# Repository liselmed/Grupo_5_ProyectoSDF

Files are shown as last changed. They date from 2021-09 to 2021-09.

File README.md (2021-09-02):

# Grupo#5 Proyecto: Smart Dairy Farming
*Sistema de monitoreo de temperatura y pH mediante una aplicación móvil para el control de la salud de la vaca.*

## Integrantes:
* Farinango Salazar Pedro
* Medina Chalén Lissette Elvira

## Descripción
Este repositorio tiene los archivos necesarios para la simulación de un sensor bolus que mide la temperatura y pH dentro del estómago de una vaca (rúmen), donde dichos datos serán enviados a través del protocolo de comunicación zigbee hacia una estación base que tendrá el objetivo de enviar credenciales y los valores de los sensores a una base de datos remota por medio de internet para que posteriormente se pueda monitorear en una aplicación móvil a través de gráficas de temperatura y pH en función del tiempo.

## Archivos Proteus
En la carpeta "Simulaciones" se tendrán dos archivos Proteus que van a representar el sensor bolus y la estación base, cabe recalcar que la versión del software es de 8.11 y para la comunicación de los módulos XBee (COMPIM) se utilizó el programa 'Virtual Serial Port', finalmente, se tiene un documento pdf que explica las simulaciones de todo el proyecto realizado.

## Archivos para la configuración de la base de datos
Para la base de datos remota se utilizó el servidor 000Webhost gratuito que posee la herramienta PhpMyAdmin, en la carpeta 'Configuraciones_Base de Datos' se tiene cada uno de los documentos .php que deben ir en File Manager de 000Webhost, los cuales permitirán hacer las peticiones post y get a la base de datos. A su vez, se tiene un archivo pdf que explica la creación de las tablas en las bases de datos con sus respectivos disparadores y relaciones entre cada una de ellas.

## Aplicación móvil
La aplicación movil se realizó en el software Android Studio y para acceder a ella se debe descargar todos los archivos de la carpeta 'Proyecto-SDF' los cuales permitirán el monitoreo de la salud de una vaca a través de gráficas de temperatura y pH en función del tiempo.

## Explicación del proyecto
Finalmente, se tiene un archivo Link_Exposicion.txt en el cual se adjunta el link de Youtube con la explicación del proyecto de forma breve y las respectivas simulaciones en tiempo real.

## Proyecto Smart Dairy Farming
-Archivo Proteus del sensor bolus

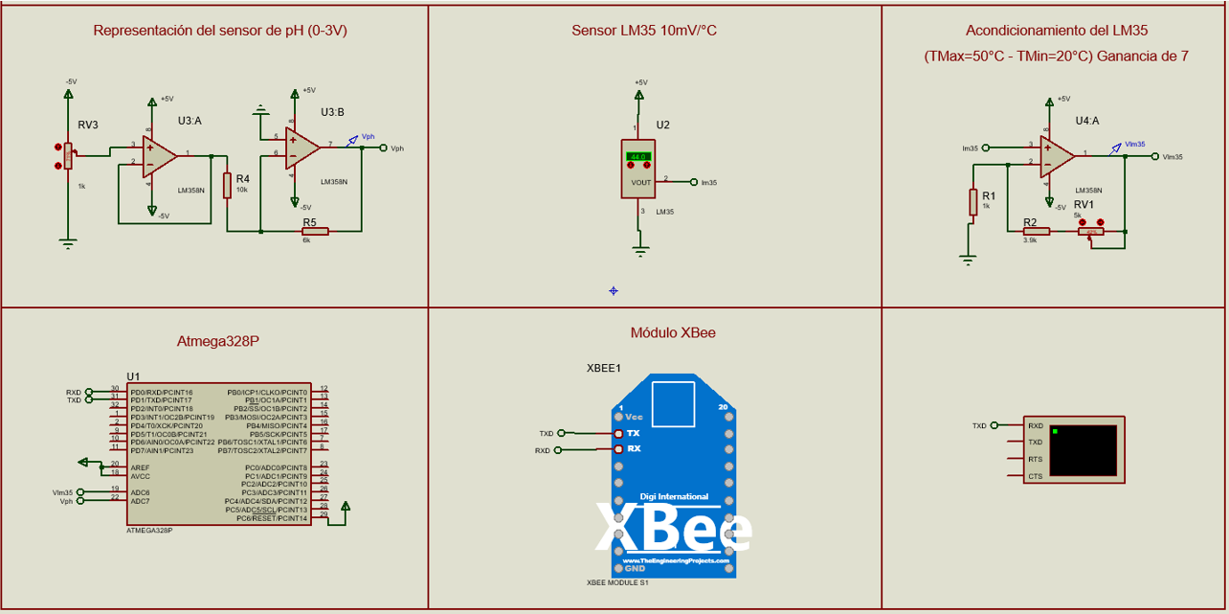
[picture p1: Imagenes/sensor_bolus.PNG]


-Archivo Proteus de la estación base

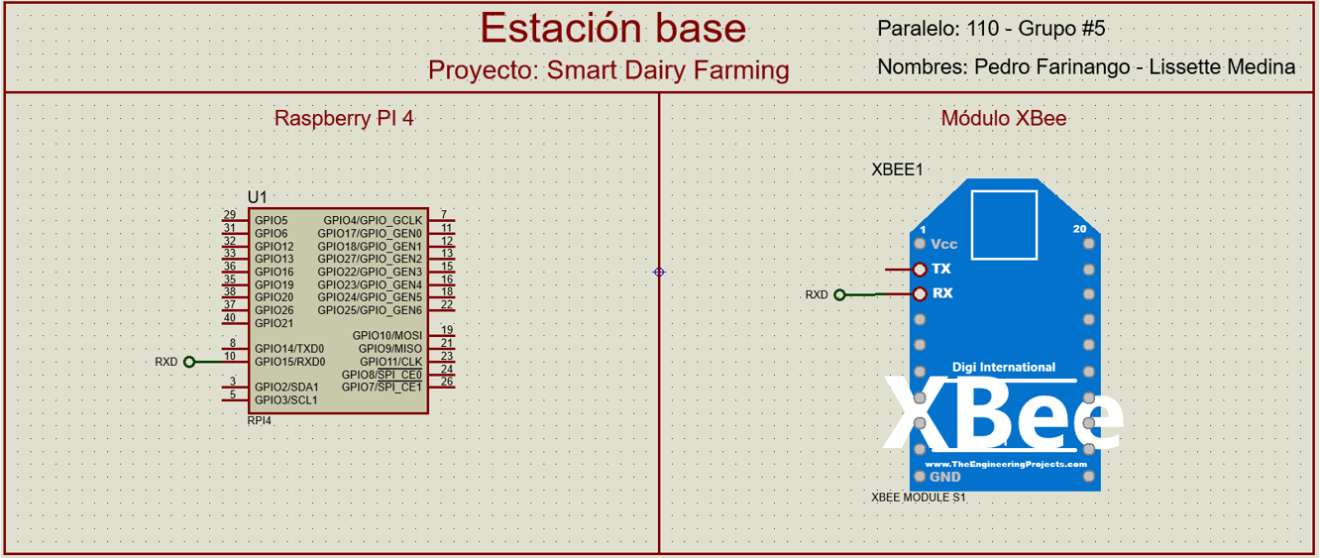
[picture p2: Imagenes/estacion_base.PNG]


-Aplición móvil en Android Studio

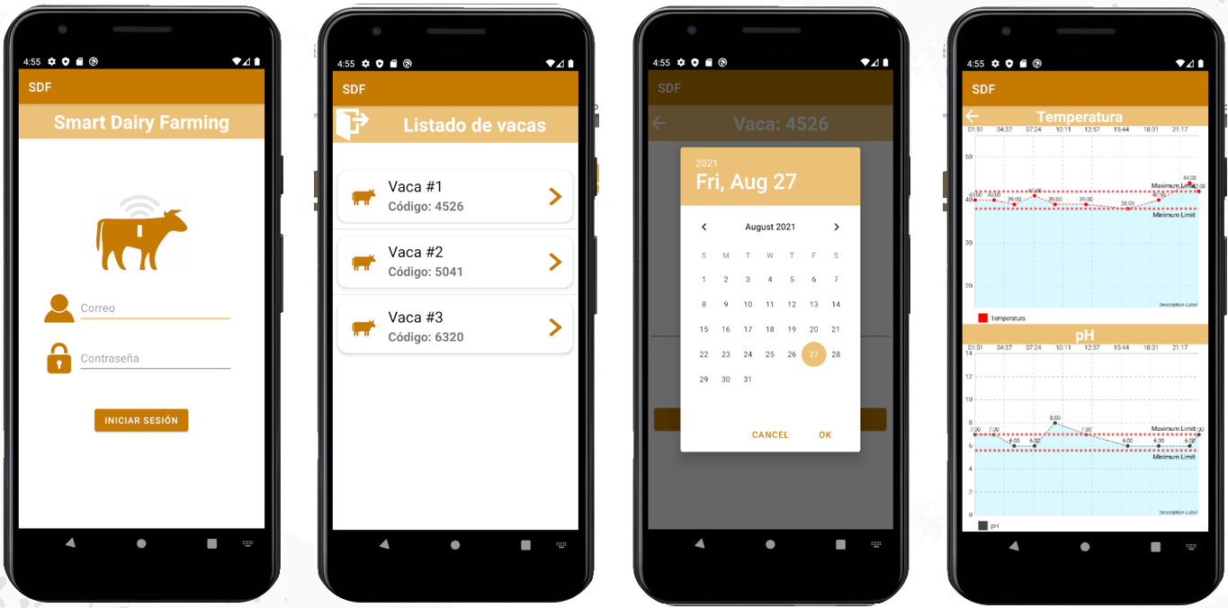
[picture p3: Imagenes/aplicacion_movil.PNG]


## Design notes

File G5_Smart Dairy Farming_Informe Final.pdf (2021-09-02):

SMART DAIRY FARMING | 1

Smart Dairy Farming: Health care

Farinango Salazar Pedro

Medina Chalen Lissette

Escuela Superior Politécnica del Litoral (ESPOL)

Facultad de Ingeniería en Mecánica y Ciencias de la Producción (FIMCP)

Notas del autor

Farinango Salazar Pedro, Estudiante de Ingeniería Mecatrónica, contacto: farinang@espol.edu.ec

Medina Chalen Lissette, Estudiante de Ingeniería Mecatrónica, contacto: liselmed@espol.edu.ec

Profesor Teórico: Allison Constantine

Profesor Práctico: Federico Domínguez

2021-1S

Introducción

Actualmente se buscan mejoras en los diferentes procesos industriales que realiza el ser

humano, una de ellas es la automatización, que surge debido a la gran demanda de los productos

que se consumen diariamente. En el caso de la industria lechera, gestionar una gran cantidad de

vacas supone algunos problemas para los encargados del ganado, debido a que se debe mantener

un control sobre el animal en diferentes aspectos, principalmente la salud. En este presente

proyecto se trata de detectar a través de parámetros como el pH y temperatura del rumen de la

vaca la enfermedad denominada Acidosis ruminal subclínica (SARA) que produce un

decaimiento en la digestibilidad de la fibra del rumen, y a su vez, tiene efectos negativos en el

rendimiento de la leche, como por ejemplo, la disminución de producción y su contenido de

grasa, de la misma manera se produce un costo elevado en la alimentación debido a la

deficiencia alimenticia producida por la SARA y, en el peor de los casos, la muerte del bovino.

La solución de este proyecto se basa en un sensor de pH y temperatura que estarán

envueltos en una resina a prueba de ácidos, la cual será insertada mediante una fístula ruminal

hasta llegar al rumen de la vaca, a través de eso se recopilan datos de los sensores

frecuentemente y son enviados mediante una conexión inalámbrica Zigbee hasta un Gateway,

que posteriormente traslada los valores a una nube y por medio de una aplicación móvil se

observan gráficas de temperatura y pH del rumen en función del tiempo, con la finalidad de

prevenir la SARA y así monitorear la salud de la vaca de forma precisa y eficiente.

Antecedentes

En la actualidad, la demanda de productos lácteos ha aumentado debido al crecimiento

poblacional. Según estudios anteriores, el consumo de productos lácteos está creciendo en países

subdesarrollados, donde el 80% de estos proviene de pequeños agricultores, los cuales no

cuentan con la tecnología necesaria para afrontar la mayor demanda del mundo.

Los productores de leche atraviesan limitaciones en cuanto a la gestión, capacidad de

producción y labores agrícolas correspondientes al ganado bovino, las cuales suponen un gran

costo. De acuerdo con estas limitaciones y desafíos, es necesario que el productor de leche

aumente su productividad y eficiencia abarcando recursos tecnológicos avanzados que le

permitan un monitoreo inteligente del manejo del ganado y así prevenir enfermedades, detectar

problemas de salud, entre otros.

Dentro de las investigaciones realizadas para el desarrollo de granjas lecheras inteligentes

se han considerado diferentes ontologías para permitir el análisis de datos y han implementado

proyectos que involucran sensores para monitorear diferentes actividades de las vacas, como es

el caso de SmartHerd, el cual analiza el comportamiento animal y control de la salud de la vaca,

los cuales constituyen el principal desafío para los productores de leche. Los autores describieron

diferentes áreas clave para el manejo de la fertilidad con ayuda de los sensores, ya que un buen

manejo de la fertilidad permitiría una mayor reproducción para de esa forma satisfacer la

creciente demanda del mercado.

Finalmente, las técnicas automatizadas en el ordeño, la alimentación y salud del bovino

son técnicas clave que pueden ser el futuro de una granja lechera inteligente y, a su vez, la razón

de una mayor producción de leche.

Objetivos

Objetivo General

Monitorear la salud y optimizar la alimentación de las vacas a través de la medición de

temperatura y pH dentro del rumen para la detección de SARA.

Objetivos Específicos

- Representar el funcionamiento de un sensor bolus mediante el uso de dos sensores de

temperatura y pH para la medición de los parámetros respectivos y el control de la salud de la

vaca.

- Registrar y transmitir los datos de temperatura y pH del rumen mediante el protocolo de

comunicación inalámbrica ZigBee para su visualización en una aplicación móvil.

- Determinar el efecto en la eficiencia alimenticia de tres vacas a través de la variación en el

aporte de nutrientes utilizando los datos obtenidos de un sensor de temperatura y de pH en una

aplicación móvil.

Smart Dairy Farming: Health care

Problemática

La ganadería lechera puede estar expuesta a enfermedades y por ende controlar cada

animal de forma continua es complicado, debido a que requiere mucho tiempo, y esto, es un

factor determinante en el cuidado de las vacas. Una de las enfermedades más comunes y que

repercute en la producción de la leche es la acidosis ruminal subclínica (SARA) (Osama, 2020),

la cual es un trastorno metabólico y nutricional difícil de diagnosticar que provoca la

disminución del pH del rumen con valores menores a 5.6 y un aumento en la temperatura mayor

a 42 °C (Omar Araujo, 2007). Dicha enfermedad afecta la eficiencia alimenticia y disminuye la

producción de leche y su contenido de grasa, por lo que los costos de alimentación incrementan

debido a que cada disminución de pH de 0.1 reduce la digestibilidad de la fibra en 3.6% (Cardo,

2020), cabe recalcar que episodios breves de 30 minutos de SARA no influyen directamente en

la reducción de la digestibilidad de la fibra sino en intervalos de 3 o 4 horas.

Descripción de por qué escogió la solución

En el Ecuador, la creciente demanda de productos lácteos ha generado complicaciones en

la gestión del ganado dentro del sector de ganadería lechera, donde los pequeños productores de

leche no cuentan con las herramientas necesarias para satisfacer dicha demanda, por lo que un

control inteligente de la vaca supone un gran aporte para estas personas, las cuales podrían

monitorear de forma continua la temperatura y pH de sus vacas para detectar tempranamente

enfermedades como el SARA, y de esa forma evitar gastos en los costos alimenticios y pérdidas

que afecten la producción lechera, ya que el SARA conlleva a otras enfermedades y también

pérdidas económicas en la industria lechera, con costos estimados en alrededor de USD 1.12 por

día y por vaca afectada (Nutrex, 2021).

De esta manera se podría ayudar a los productores a obtener un historial de la salud de

sus vacas y a tomar las medidas necesarias para evitar consecuencias graves, ya que actualmente

se aplican métodos tradicionales que implican mayores gastos y recursos, además de provocar

estrés e incomodidad en el bovino.

Finalmente, el proyecto como tal no se ha implementado en el país, por lo que sería una

propuesta innovadora.

Descripción de los elementos

Selección

De acuerdo con los elementos seleccionados, los cuales se encuentran detallados en la

Tabla 1 de la sección Tablas, se pretende diseñar dos tipos de carcasas que estarán ubicadas

dentro del rumen de la vaca y otra en la estación base (Gateway). La carcasa dentro de la vaca

consiste en un dispositivo cilíndrico (bolus) hecho de polioximetileno (POM) y recubierto con

una resina a prueba de ácidos (moonsyst International, 2021), esta carcasa tendría una protección

IP57, ya que los elementos estarán encapsulados, pero los sensores de temperatura y pH no

estarán completamente cubiertos.

Ilustración 1. Representación del dispositivo Bolus.

La carcasa ubicada en la estación base para la comunicación inalámbrica consiste en un

termoplástico de material ASA con una protección IP51, debido a que el dispositivo no estará

completamente cubierto porque tendría puertos abiertos para la alimentación de la Raspberry Pi

y la conexión ethernet.

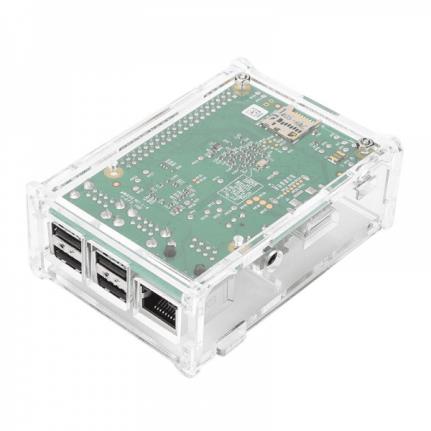
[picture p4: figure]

Ilustración 2. Carcasa para Raspberry Pi.

Componentes de hardware y software

Componentes de hardware:

El bolus, el cual será insertado en el rumen de la vaca, contiene los sensores de temperatura y de

pH, el atmega328P, el módulo XBee y la batería recargable de 5V de material Litio-polímero.

Los sensores se encargarán de medir la temperatura y el pH del rumen en intervalos de 15

minutos, tiempo determinado según un estudio previamente hecho sobre la relación entre pH y la

temperatura en el fluido ruminal para detectar cambios sobre una acidosis ruminal inducida

(Pedro García, 2015).

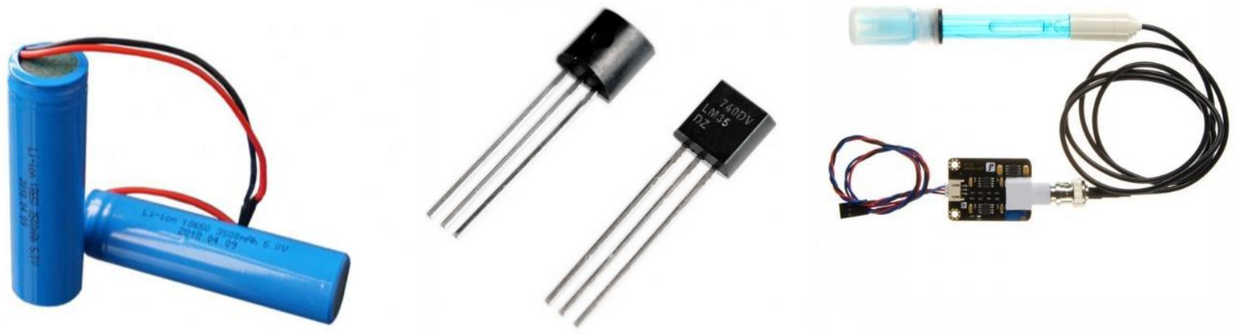
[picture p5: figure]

a) | b) | c)

Ilustración 3. a) Batería de 5V, b) Sensor LM35, c) Sensor pH SEN0161.

Los valores analógicos de los sensores serán procesados por el microcontrolador Atmega328P

para luego ser receptados por el módulo XBee End Device.

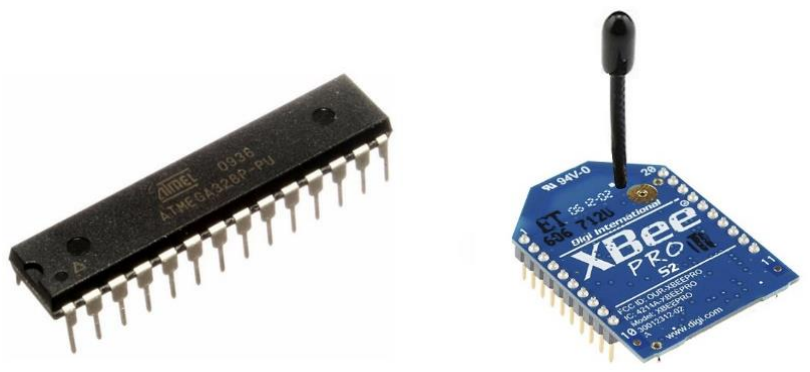
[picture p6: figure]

a) b)

Ilustración 4. Microcontrolador ATmega328P, b) Módulo Xbee End Device.

Posteriormente se da la comunicación Zigbee entre el dispositivo final y un módulo XBee

Coordinador que servirá para almacenar los datos enviados, este estará en la estación base

conectado a una Raspberry Pi para transmitir la información de los sensores a una base de datos.

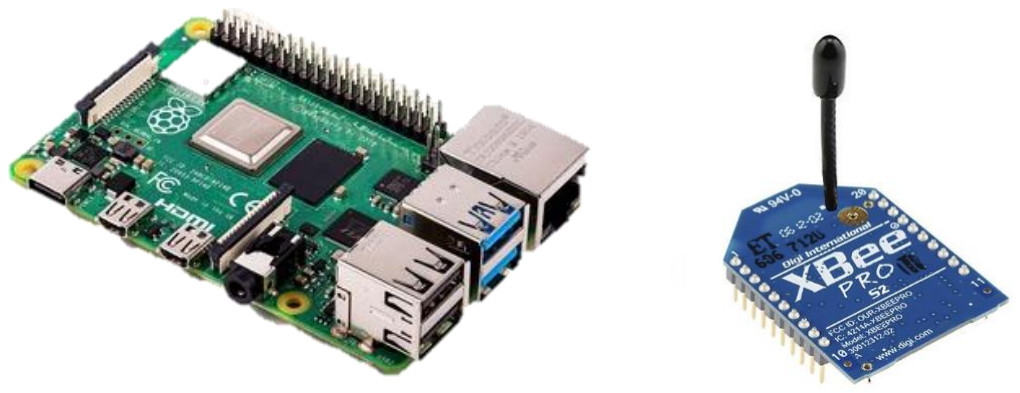
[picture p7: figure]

a) b)

Ilustración 5. a) Raspberry Pi 4, b) Módulo Xbee Coordinador.

Componentes de software:

Para la simulación del sistema de monitoreo y transmisión de datos se usará el software Proteus,

con el inconveniente de que se tendrá que utilizar un potenciómetro para representar el sensor de

pH con su respectivo acondicionamiento, debido a que en Proteus no se encuentra ningún sensor

de este tipo.

Para la gestión de base de datos se usará phpMyAdmin en la página 000WebHost.com,

posteriormente la información será enviada a una aplicación móvil creada en el software Android

Studio para el monitoreo de las condiciones del rumen de la vaca mediante la visualización de

los datos de temperatura y pH en tiempo real.

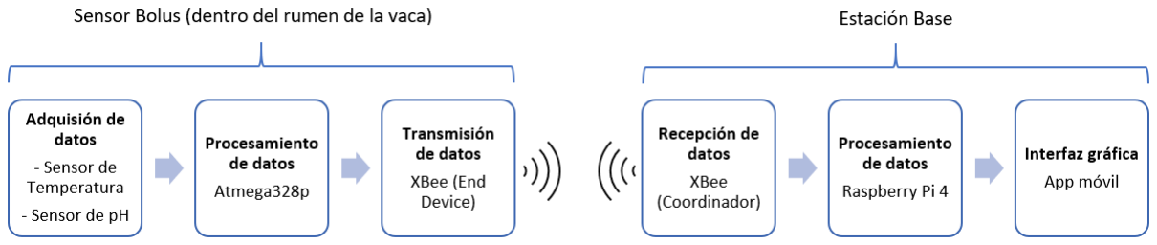
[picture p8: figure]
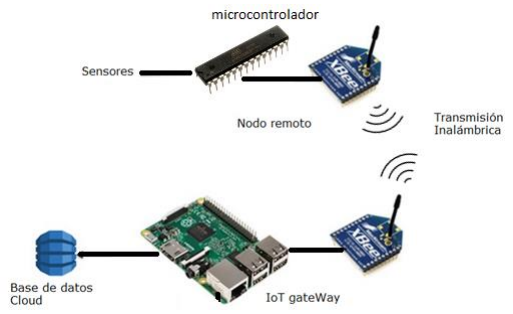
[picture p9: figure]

Ilustración 6. Diagrama de bloques del monitoreo y transmisión de datos.

Tabla de componentes y precios

La lista de los componentes con sus precios se encuentra en la Tabla 1 de la sección

Tablas.

Instalación y diseño

La fabricación de las carcasas para el sensor Bolus y la estación de base podrían hacerse

en https://www.plastinmega.com/.

Además, de acuerdo con el diseño de los PBCs realizados, la impresión de los mismos se

cotizó en la página JLCPCB (https://jlcpcb.com/) y su obtuvieron los siguientes precios:

PCB: Sensor bolus (Sensor de pH y temperatura, XBee End Device, ATmega328P,

batería)

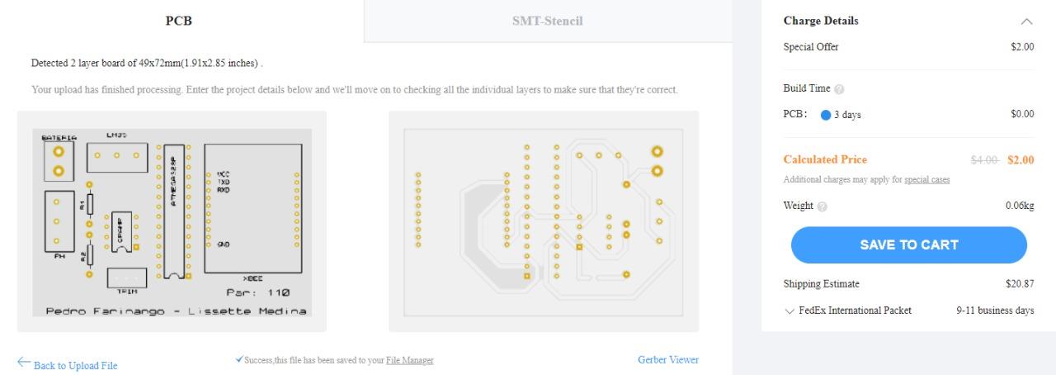
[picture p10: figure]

PCB: Estación base (Raspberry Pi 4, XBee coordinador)

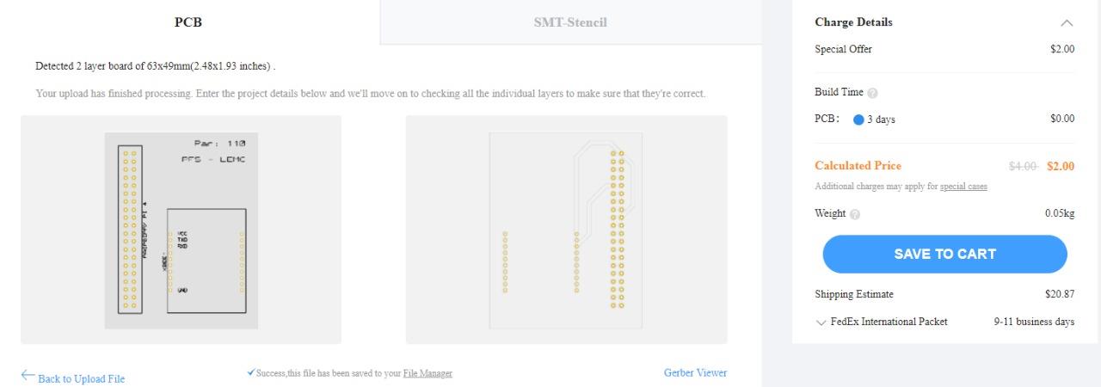
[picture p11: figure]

Aplicaciones a futuro

Se pretende realizar mejoras como:

- Ampliar la cobertura inalámbrica a través de repetidores de señal para el caso de

granjas con terrenos amplios.

- Suplir la batería recargable actual por una de mayor capacidad para una larga

duración dentro del rumen de la vaca.

- Compatibilidad con iOS e implementación en la web.

- Implementar una base de datos local en granjas lecheras que no tengan acceso a

internet.

Conclusiones

Se representó el funcionamiento de un sensor bolus mediante el uso de sensores de

temperatura y pH para la obtención de dichos parámetros y por ende controlar la salud de la

vaca, de manera que se midieron los valores analógicos de ambos sensores mediante el

microcontrolador ATmega328P para posteriormente realizar una comunicación serial con un

módulo XBee y enviar la información a una estación base.

Se realizó el acondicionamiento de las señales analógicas de los sensores de pH y

temperatura para la correcta lectura y conversión de dichos valores en el ATmega328P.

Se representó una estación base mediante la Raspberry PI 4 y un módulo XBee

coordinador para el registro y transmisión de los datos de temperatura y pH del rumen de la vaca

hacia una base de datos y visualizarlos en una aplicación móvil.

Se obtuvieron las gráficas de temperatura y pH del rumen de la vaca en función del

tiempo mediante una aplicación móvil que permitió el análisis del efecto en la eficiencia

alimenticia de tres vacas a través de una disminución del pH.

Recomendaciones

Es recomendable que, al realizar las mediciones de temperatura y pH mediante los

sensores, se analice correctamente los puertos analógicos a utilizar en el ATmega328P para de

esa forma habilitar los registros correspondientes que permitan la lectura y conversión analógica

de dichos valores.

Es importante entender que, en la vida real, el registro de lectura se cada 15 minutos y el

período de tiempo para determinar si existe o no la enfermedad de SARA requiere que las condiciones se presentan al menos durante 3 horas, por lo que es recomendable que en la

simulación se evidencie dicho tiempo para realizar el respectivo análisis.

Para el funcionamiento de la aplicación móvil, es importante que se realicen

correctamente las peticiones POST y GET en la Raspberry Pi y en la aplicación Android

respectivamente para obtener los datos de pH y temperatura y realizar las gráficas sin ningún

error.

Es recomendable establecer correctamente la ganancia necesaria en el acondicionamiento

de las señales analógicas para obtener una buena resolución en los valores medidos por el

ATmega328P.

References

Osama, M., Saad, M., Jamshaid, M., Qaiser, G. and Pasha, M., 2020. IoT for Development of

Smart Dairy Farming. [online] Pakistan: Maria Rosaria Corbo. Available at:

<https://doi.org/10.1155/2020/4242805> [Accessed 9 July 2021].

Araujo, O. and Vergara, J., 2021. Propiedades físicas y químicas del rumen. [online]

Bioline.org.br. Available at: <http://www.bioline.org.br/pdf?la07044> [Accessed 9 July

2021].

Pardo, L., 2020. Cómo abordar la acidosis y los peligros de la SARA. [online] biomin.net.

Available at: <https://bmeditores.mx/ganaderia/como-abordar-la-acidosis-y-los-peligros-

de-la-sara/> [Accessed 9 July 2021].

Real, L., 2019. Industria Láctea con mejores condiciones de producción. Gestión digital, [online]

(226), pp.36-39. Available at:

<https://revistagestion.ec/sites/default/files/import/legacy_pdfs/226_004.pdf> [Accessed

10 July 2021].

Nogami, H., Arai, S., Okada, H., Zhan, L. and Itoh, T., 2017. Minimized Bolus-Type Wireless

Sensor Node with a Built-In Three-Axis Acceleration Meter for Monitoring a Cow’s

Rumen Conditions. [online] MDPI. Available at: <https://doi.org/10.3390/s17040687>

[Accessed 11 July 2021].

Ibarra, N., 2015. Desarrollo de un sistema de monitoreo intra-rumial en tiempo real de variables

fisiológicas para ser empleado en estudios sobre adaptación bovina ante el cambio

climático en la ganadería tropical del sureste mexicano. [online]

Repositorioinstitucional.buap.mx. Available at:

<https://repositorioinstitucional.buap.mx/handle/20.500.12371/2283> [Accessed 11 July

2021].

International, M., 2021. Moonsyst - Smart Rumen Bolus. [online] Moonsyst. Available at:

<https://moonsyst.com/bolus> [Accessed 15 July 2021].

Wiki.dfrobot.com. 2021. Gravity__Analog_pH_Sensor_Meter_Kit_V2_SKU_SEN0161-V2-

DFRobot. [online] Available at:

<https://wiki.dfrobot.com/Gravity__Analog_pH_Sensor_Meter_Kit_V2_SKU_SEN0161

-V2#More_Documents> [Accessed 15 July 2021].

García, P., Hernández, A., Zamora, A. and Díaz, H., 2021. Diseño de un sistema de

comunicación inalámbrica para ser usado en el monitoreo de temperatura y pH del

rumen de bovinos. [online] ResearchGate. Available at:

<https://www.researchgate.net/publication/284721391_DISENO_DE_UN_SISTE

MA_DE_COMUNICACION_INALAMBRICA_PARA_SER_USADO_EN_EL_

MONITOREO_DE_TEMPERATURA_Y_PH_DEL_RUMEN_DE_BOVINOS>

[Accessed 15 July 2021].

Nutrex, 2021. Endotoxinas y sara en las vacas lecheras - un círculo vicioso. Nutrex. Available at:

https://www.nutrex.eu/es/articulos/endotoxinas-y-sara-en-las-vacas-lecheras-un-

circulo-vicioso/ [Accessed August 29, 2021].

Tablas

Tabla 1

Lista de Componentes

Elemento | Marca | Modelo | Precio
Sensor de temperatura Sensor pH | Texas Instruments
| DFRobot | LM35
| | SEN0161 | $3
| | | $29.5
Microcontrolador AVR | Microchip Technology / Atmel (https://www.mouser.ec/manufacturer/atmel/) | Atmega328 | $6
Raspberry Pi | Raspberry Pi Foundation | Pi 4 Model B | $67.5
Módulo XBee Batería | DIGI
| DTP | S2C 802.15.4 RF | $38
| | | $12.6

Links de compra:

https://www.sigmagye.net/

https://ecuarobotics.com/

https://spanish.alibaba.com/product-detail/5-volt-rechargeable-lithium-polymer-battery-pack-

6000mah-for-gateway-w35044lb-laptop-1595484911.html (https://spanish.alibaba.com/product-detail/5-volt-rechargeable-lithium-polymer-battery-pack-6000mah-for-gateway-w35044lb-laptop-1595484911.html)

https://www.dfrobot.com/product-1025.html

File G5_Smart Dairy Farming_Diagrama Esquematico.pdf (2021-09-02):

Smart Dairy Farming, Proyecto#5

Paralelo: 110

Integrantes: Pedro Farinango Salazar, Lissette Medina Chalén.

Circuito Esquemático

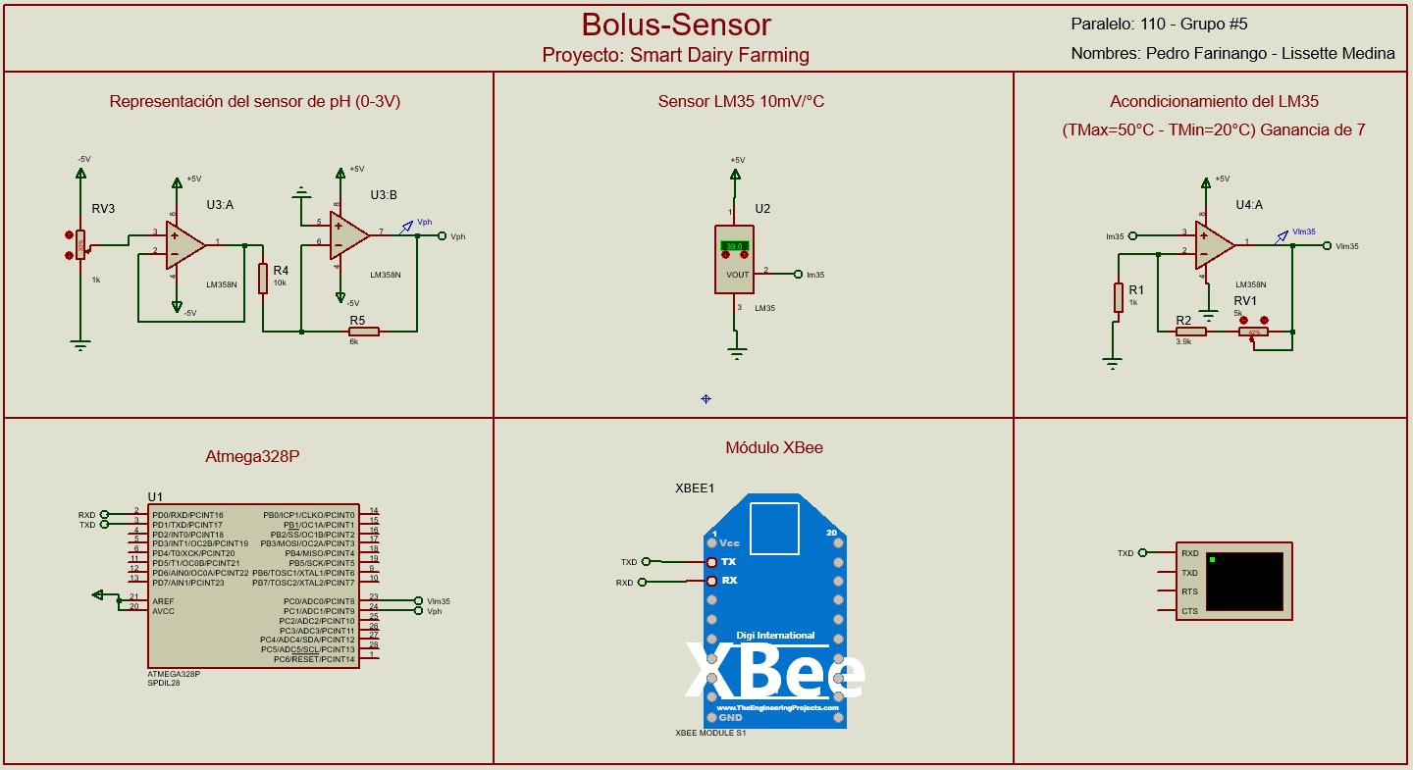
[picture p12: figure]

Circuito del bolus sensor en Proteus: tendrá el objetivo de medir los valores analógicos de los sensores de temperatura y pH por medio de un microcontrolador Atmega328P para que posteriormente realice una comunicación serial con un módulo XBee (dispositivo final) y finalmente poder enviar estos datos mediante radiofrecuencia a una estación base.

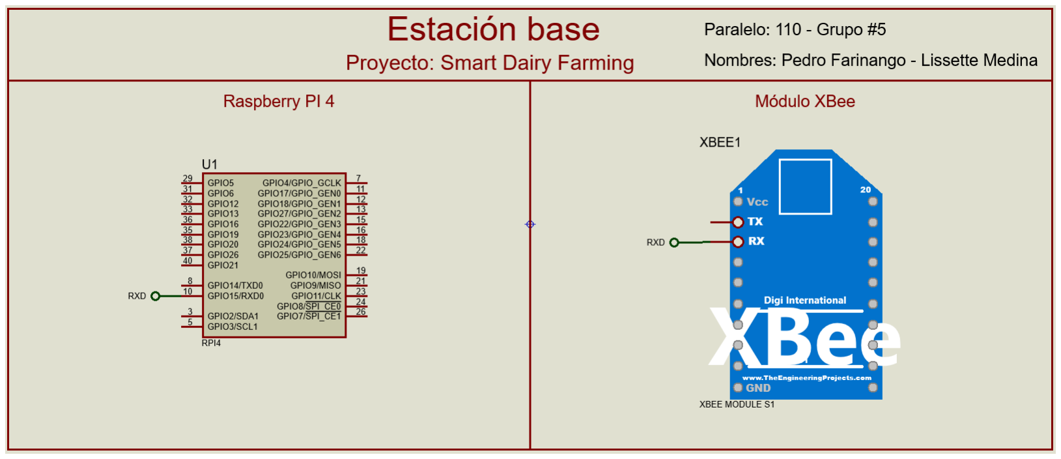
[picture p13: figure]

Circuito de la estación base en Proteus: mediante un módulo XBee (Coordinador) se obtendrán los datos de temperatura y pH enviados desde el bolus sensor, luego este módulo realizará una comunicación serial con una Raspberry PI 4 para obtener estos datos y posteriormente realizar peticiones POST hacia una base de datos remota donde se enviarán: id usuario, id vaca, temperatura, pH y fecha del envío.

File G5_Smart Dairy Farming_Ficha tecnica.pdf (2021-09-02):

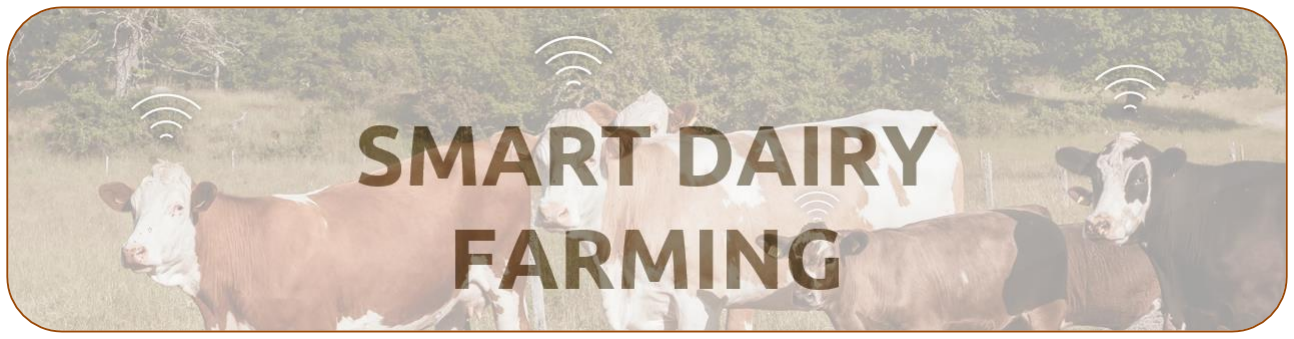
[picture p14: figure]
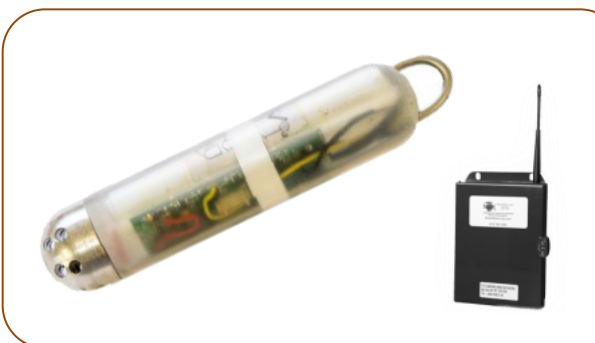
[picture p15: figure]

Especificaciones técnicas

Bolus
Voltaje: | 3.3V-5V
Corriente: | 39.3m-70.3mA
Capacidad: | 6000mAh
Potencia: | 0.35W
Temperatura: | 60°C
Rango de sensor de temperatura: | 20°C–50°C
Precisión de sensor temperatura: | 0.5°C
Rango de pH: | 0pH–14pH
Precisión de pH: | 0.5 pH
Distancia de envío de datos: | 90m
Intervalo de medición: | 15-30min
Protección IP: | IP57

Dimensiones y peso dela unidad
Dimensiones (L x D) mm | 135x35
Peso: | 200g

Base Receptora
Voltaje: | 5V
Corriente: | 600mA-1.2mA
Potencia: | 2.08W
Conexión a internet: | Cable Ethernet UTP
Protección IP: | IP51

Dimensiones y peso dela unidad
Dimensiones (L xAn xAl)mm | 105x95.6x35
Peso: | 230g

Descripción

El sensor Bolus contiene el sensor de temperatura LM35, el sensor pH SEN0161, un módulo XBee y una batería recargable. Cuenta con un microcontrolador ATmega328P que permite la conversión analógica de los valores obtenidos para su envío hacia una estación base. Ideal para obtener valores de temperatura y pH del rumen de la vaca en granjas de pequeños productores.

Beneficios
- Batería recargable con duración de 3 a 4 días.
- Opción de monitoreo remoto a través de una aplicación móvil.
- Detección temprana de enfermedad SARA y deficiencia alimenticia a través de la temperatura y pH.

# SENSOR BOLUS Y BASE RECEPTORA

0969609245 - 0982823288

liselmed@espol.edu.ec – farinang@espol.edu.ec

Lissette Medina – Pedro Farinango

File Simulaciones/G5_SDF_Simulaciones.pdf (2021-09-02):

Smart Dairy Farming, Proyecto#5

Paralelo: 110

Integrantes: Pedro Farinango Salazar, Lissette Medina Chalén.

Circuito Esquemático


Circuito del bolus sensor en Proteus: tendrá el objetivo de medir los valores analógicos de los sensores de temperatura y pH por medio de un microcontrolador Atmega328P para que posteriormente realice una comunicación serial con un módulo XBee (dispositivo final) y finalmente poder enviar estos datos mediante radiofrecuencia a una estación base.


Circuito de la estación base en Proteus: mediante un módulo XBee (Coordinador) se obtendrán los datos de temperatura y pH enviados desde el bolus sensor, luego este módulo realizará una comunicación serial con una Raspberry PI 4 para obtener estos datos y posteriormente realizar peticiones POST hacia una base de datos remota donde se enviarán: id usuario, id vaca, temperatura, pH y fecha del envío.

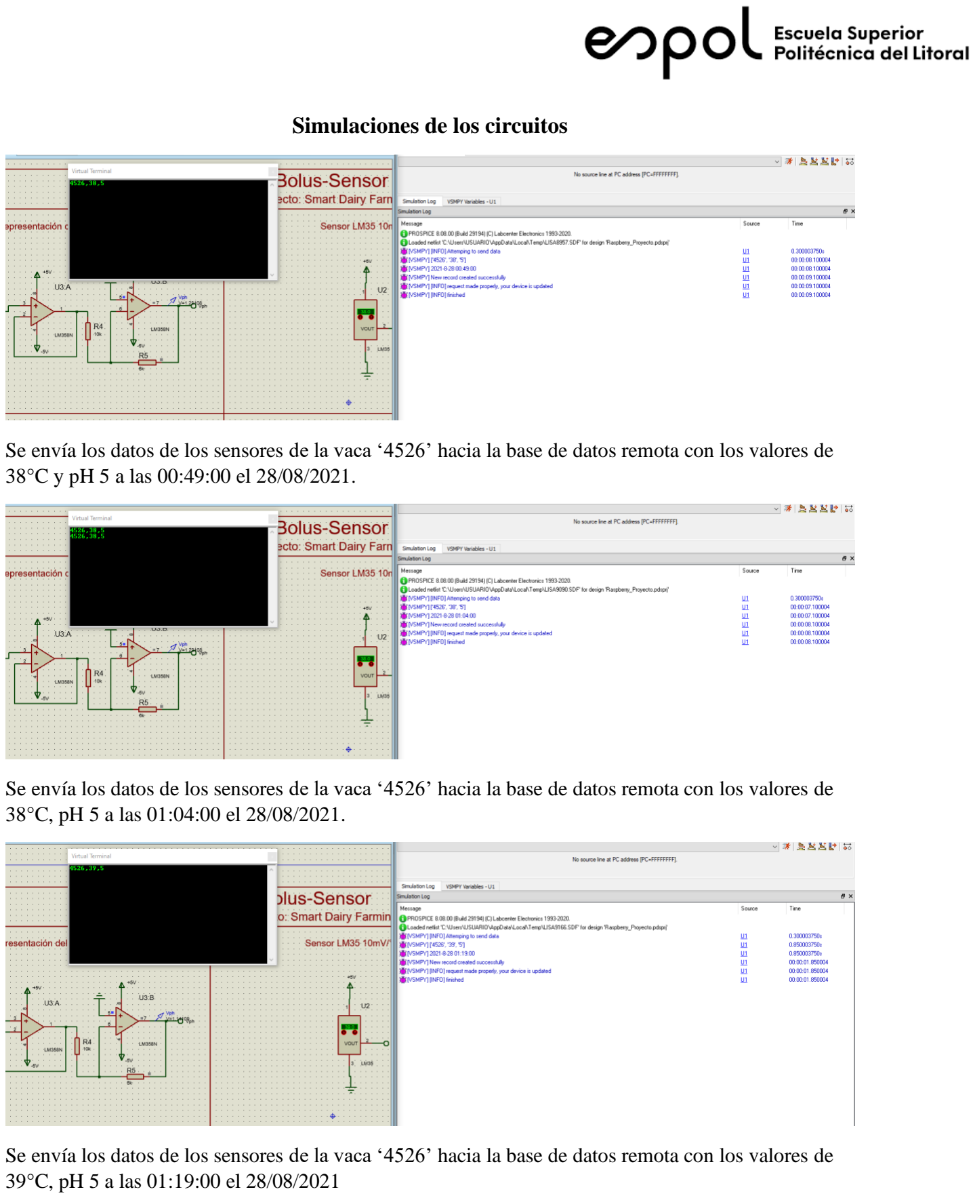
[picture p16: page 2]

Simulaciones de los circuitos

Se envía los datos de los sensores de la vaca ‘4526’ hacia la base de datos remota con los valores de 38°C y pH 5 a las 00:49:00 el 28/08/2021.

Se envía los datos de los sensores de la vaca ‘4526’ hacia la base de datos remota con los valores de 38°C, pH 5 a las 01:04:00 el 28/08/2021.

Se envía los datos de los sensores de la vaca ‘4526’ hacia la base de datos remota con los valores de 39°C, pH 5 a las 01:19:00 el 28/08/2021

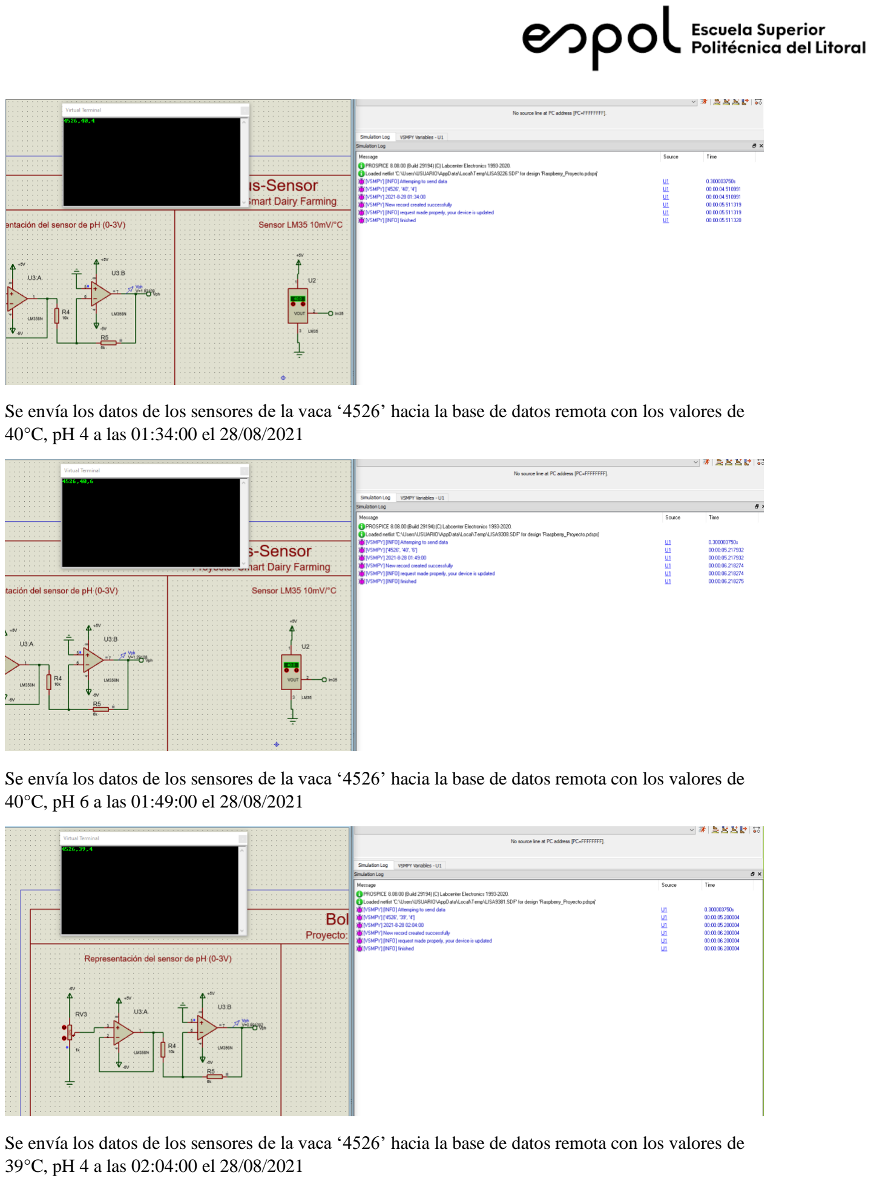
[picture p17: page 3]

Se envía los datos de los sensores de la vaca ‘4526’ hacia la base de datos remota con los valores de 40°C, pH 4 a las 01:34:00 el 28/08/2021

Se envía los datos de los sensores de la vaca ‘4526’ hacia la base de datos remota con los valores de 40°C, pH 6 a las 01:49:00 el 28/08/2021

Se envía los datos de los sensores de la vaca ‘4526’ hacia la base de datos remota con los valores de 39°C, pH 4 a las 02:04:00 el 28/08/2021

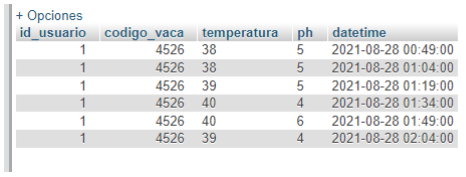
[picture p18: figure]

Se enviaron de forma correcta los datos a una tabla general llamada ‘Dato Sensor’ a la base de datos remota de PhpMyAdmin en 000WebHost.

Aplicación Móvil

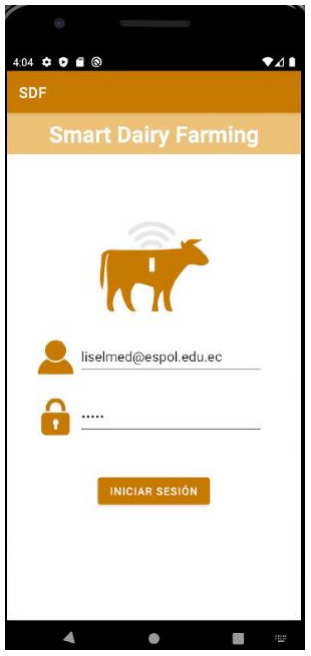
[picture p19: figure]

Se inicia sesión con el correo dado por la empresa para que de esta forma pueda tener acceso a la información de las vacas que este posea.

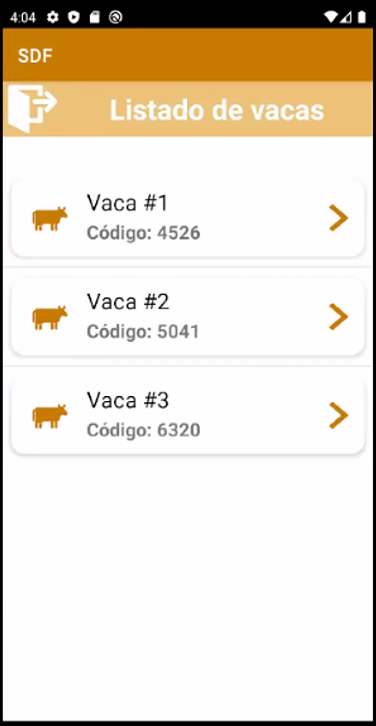
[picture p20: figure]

Una vez iniciado sesión, se muestra una lista de las vacas que posee el usuario con su código respectivo para que este pueda saber a qué vaca va a monitorear.

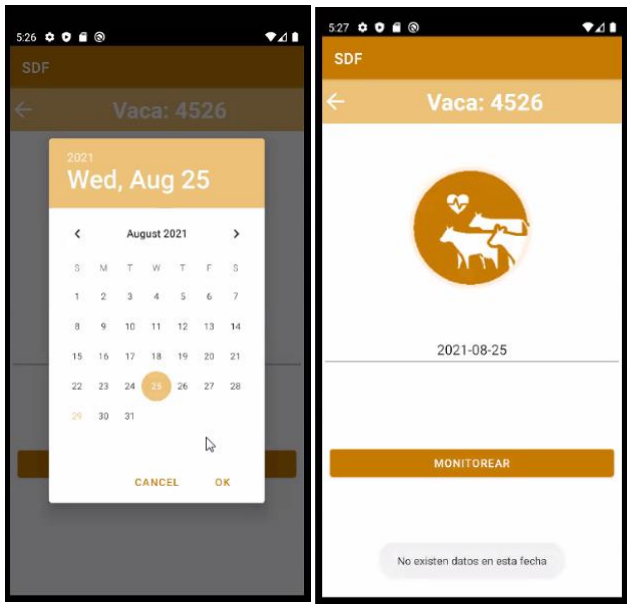
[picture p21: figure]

Una vez seleccionado una vaca, en este caso la del código 4526, se procede a escoger la fecha en la cual se desea monitorear al animal, si no existen valores en esa fecha se muestra un mensaje que menciona que no existen datos para esa fecha seleccionada.

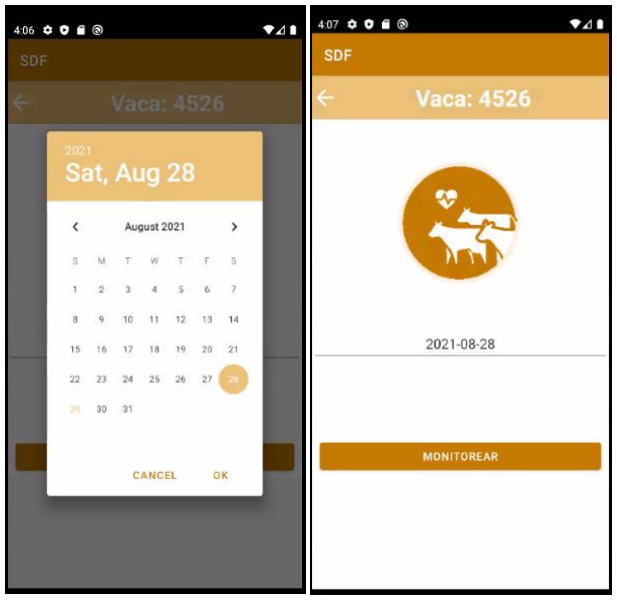
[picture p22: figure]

Si se selecciona una fecha correcta, es decir, donde si existan datos registrados, se procede a presionar el botón ‘Monitorear’ para observar las gráficas de temperatura y pH de la vaca.

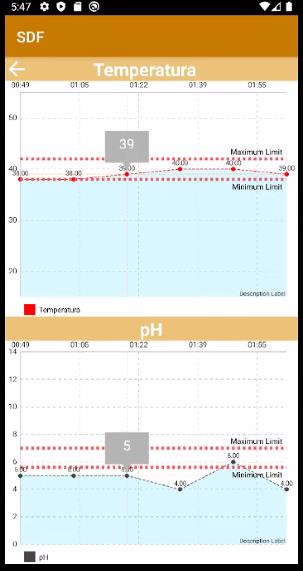
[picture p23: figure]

Se muestran las gráficas de temperatura y pH de la vaca en la fecha seleccionada. Es importante mencionar que se proporciona los límites máximos y mínimos de cada parámetro mediante líneas discontinuas de color rojo para que el usuario tenga en cuenta en qué estado está la vaca.

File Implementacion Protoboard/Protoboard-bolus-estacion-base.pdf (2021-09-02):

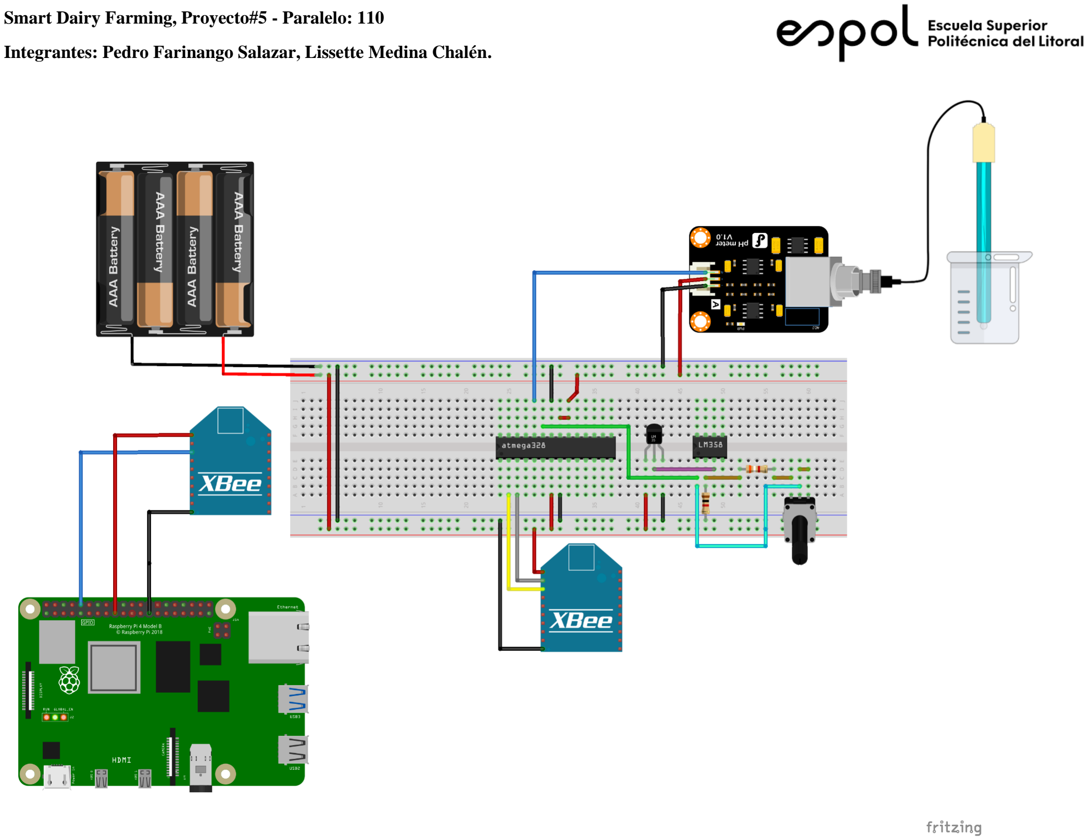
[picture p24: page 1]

Smart Dairy Farming, Proyecto#5 - Paralelo: 110

Integrantes: Pedro Farinango Salazar, Lissette Medina Chalén.

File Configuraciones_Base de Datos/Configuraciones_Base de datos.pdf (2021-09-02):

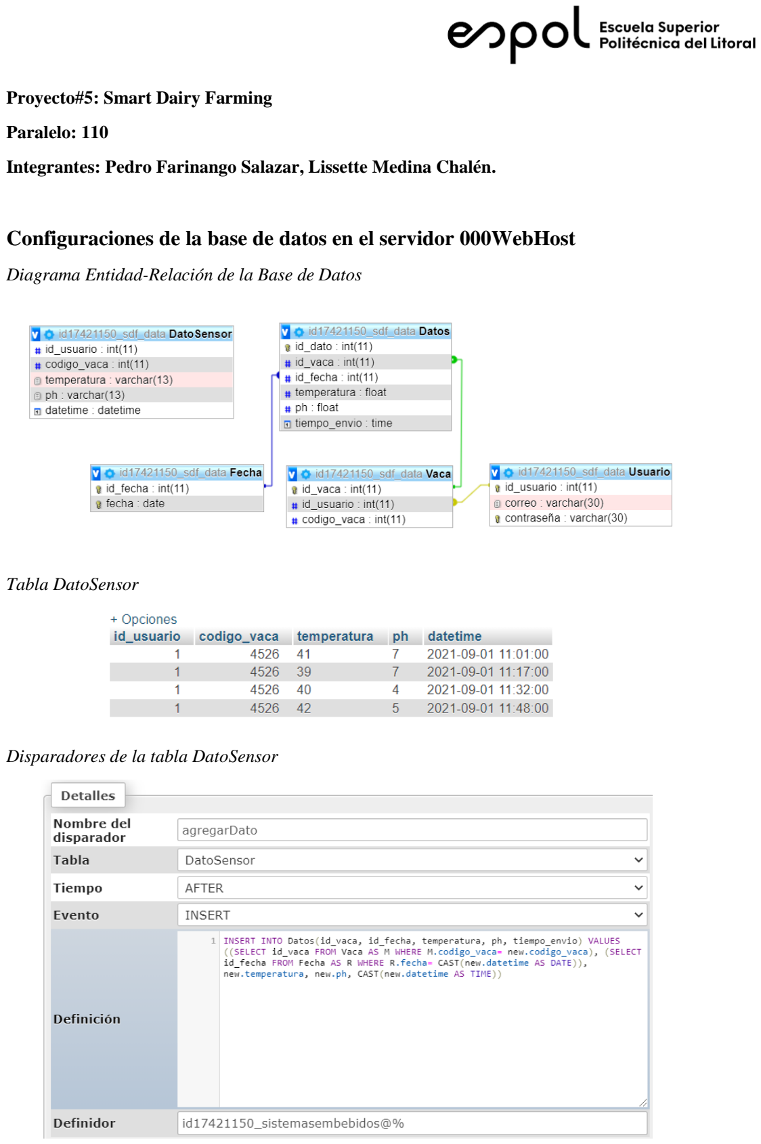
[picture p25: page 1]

Proyecto#5: Smart Dairy Farming

Paralelo: 110

Integrantes: Pedro Farinango Salazar, Lissette Medina Chalén.

Configuraciones de la base de datos en el servidor 000WebHost

Diagrama Entidad-Relación de la Base de Datos

Tabla DatoSensor

Disparadores de la tabla DatoSensor

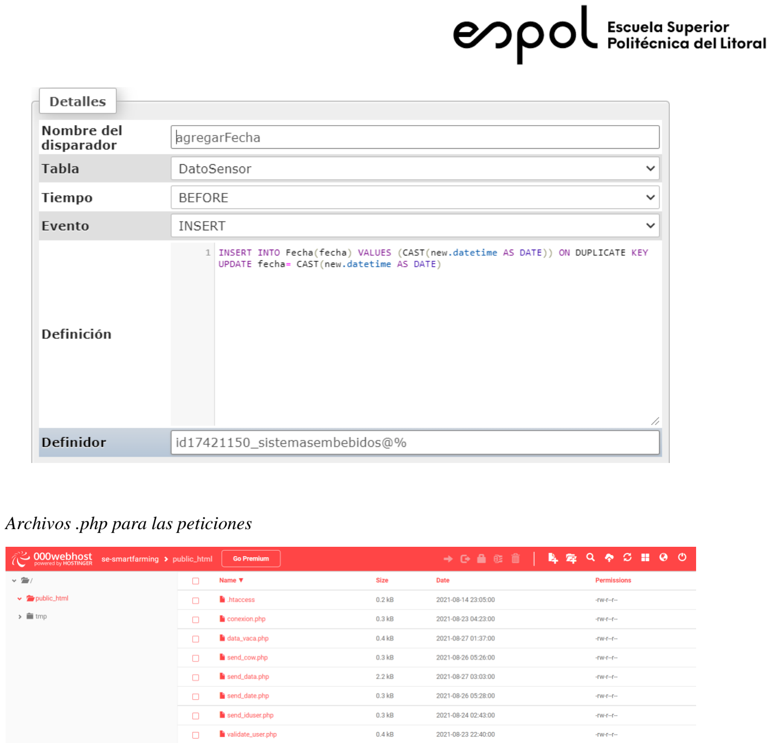
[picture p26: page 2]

Archivos .php para las peticiones

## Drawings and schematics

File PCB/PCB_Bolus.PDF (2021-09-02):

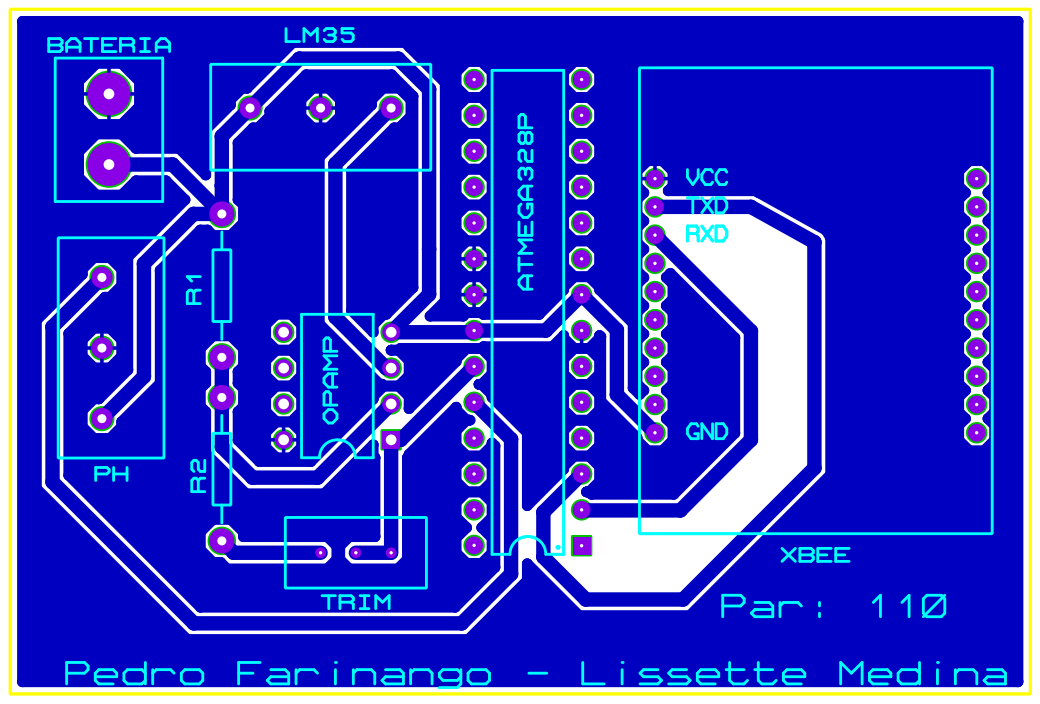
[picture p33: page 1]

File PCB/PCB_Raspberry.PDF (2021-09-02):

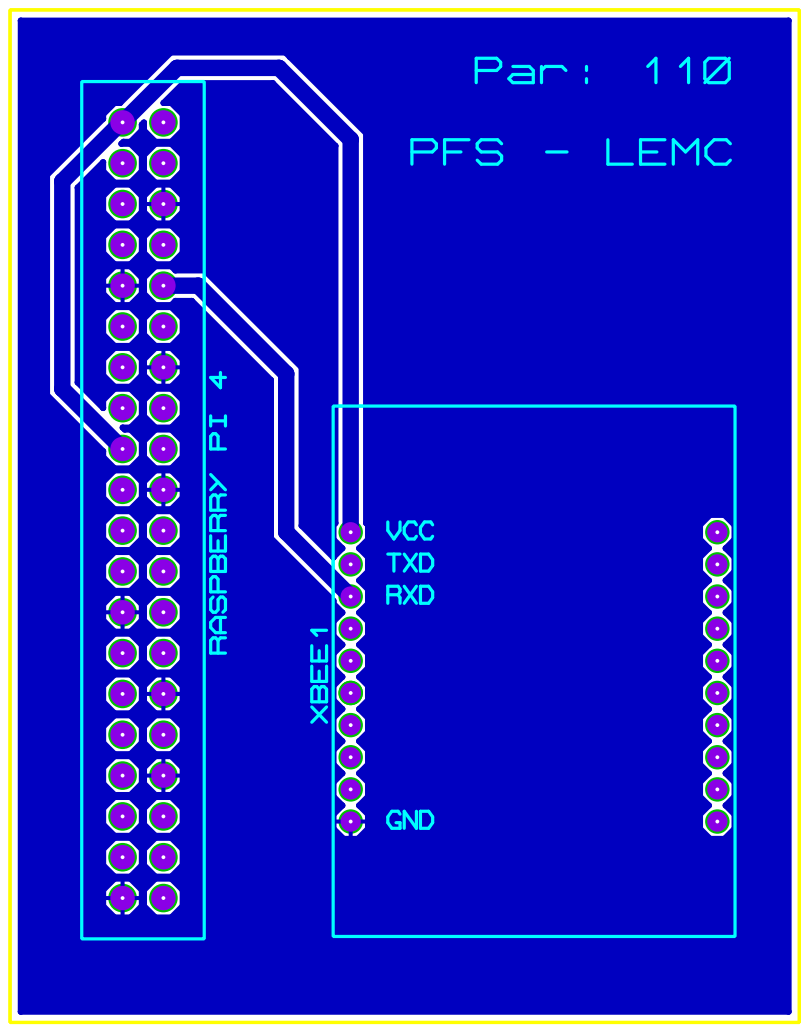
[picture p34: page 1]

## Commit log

2021-09-02 Aplicación móvil de monitoreo en Android.
2021-09-02 Documento pdf de la ficha técnica.
2021-09-02 Configuraciones de la Base de Datos en 000WebHost.
    Diagrama Entidad-Relación, tablas, Triggers, archivos .php.
2021-09-02 Implementación en Protoboard.
    Documento pdf y archivo de Fritzing.
    [Protoboard-bolus-estacion-base.fzz]
2021-09-02 Archivos PCB.
    Pdf de los pcb, archivos proteus, archivos 3DS.
2021-09-02 Archivos de simulación.
    Archivos proteus y pdf.
2021-09-02 Link de Youtube.
